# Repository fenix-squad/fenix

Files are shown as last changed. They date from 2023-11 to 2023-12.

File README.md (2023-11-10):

# Что такое Fenix?

Fenix - модель лазерного проектора, разработанная с нуля на олимпиаде
\"Технологии успеха\" командой 548-I. Данный проектор предназначен для
показа лазерных шоу и вывода различных символов на любую твердую
поверхность. Fenix является дешёвым и качественным продуктом, готовым к
использованию сразу после покупки.

# Устройство проектора.

## Материалы

Данный проектор изготовлен из 2 моторов Nema 17, esp 32-S2,micro sd
карты, соединительных проводов и других компонентов. В устройстве
использованы проверенные и современные комплектующие, что обеспечивает
долгую и качественную работу продукта.

## Программное обеспечение

Программное обеспечение написано на языке C++ профессиональными
разработчиками, которые оптимизировали программу. Это позволяет с
комфортом работать с проектором.

## Пользовательский интерфейс

Пользователь может управлять проектором с помощью web-приложения. Оно
написано с помощью фреймворка Svelte на Typescript, а также имеет
красивый и понятный дизайн. В web-приложении есть несколько режимов
работы: «Фигуры», «Текст», «Прямые линии», «Холст».

# Преимущества

-   Fenix собран из качественных комплектующих, которые проверяются
    перед установкой.

-   Доступная цена

-   Понятное управление проектором

# Цена устройства

  Наименование                Цена за штуку в рублях   количество   Сумма
  --------------------------- ------------------------ ------------ -------
  Мотор Nema 17               500                      2            1000
  Драйвер для мотора A4988    70                       2            140
  Esp 32-S2                   150                      1            150
  Триггер быстрой зарядки     50                       1            50
  Корпус устройства           200                      1            200
  Micro Sd карта              80                       1            80
  Модуль для micro Sd карты   20                       1            20
  Провода                     50                       да           50
  Макетная плата              90                       1            90
  Лазер                       100                      1            100
  Детали из пластика          100                      1            100
  Зеркала                     2                        2            4
  Работа                                                            1500
  Прочие расходы              100                      1            100
  Итог:                                                             3584
:::

# Заключение

За неделю наша команда разработала многофункциональный проектор по
доступной цене. Мы знаем что многое можно доработать, но мы считаем, что
уже сейчас нашим продуктом можно пользоваться с комфортом, и создавать
качественные лазерные шоу.

# Благодарность

Наша команда выражает благодарность: **Аверкиной Марине Ильиничне,
Диордице Александру Александровичу, Кудрявцеву Валерию Рудольфовичу,
Бакуну Алексею Дмитриевичу**, а также администрации и педагогическому
коллективу школы №548 за оказанную помощь и поддержку участникам
команды.

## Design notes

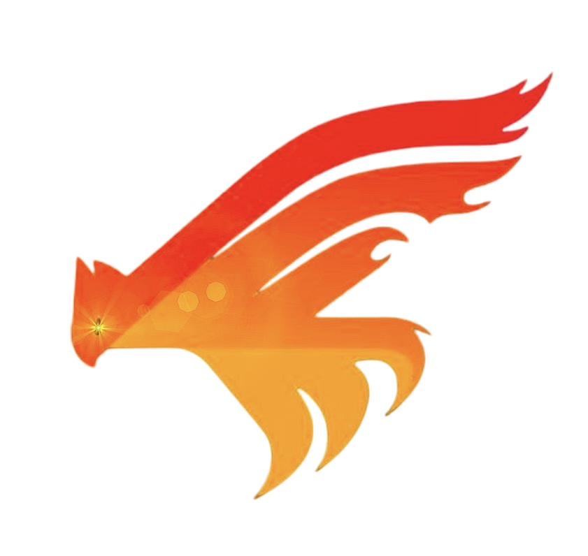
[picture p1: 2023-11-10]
assets/Imagies/Fenix.jpeg

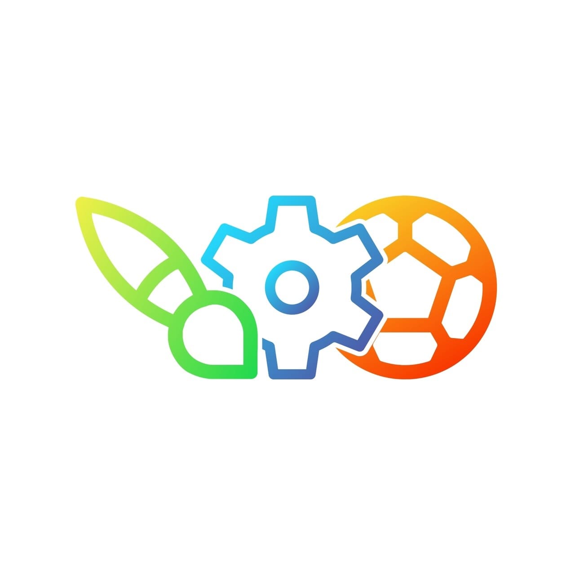
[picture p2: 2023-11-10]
assets/Imagies/BTO.jpeg

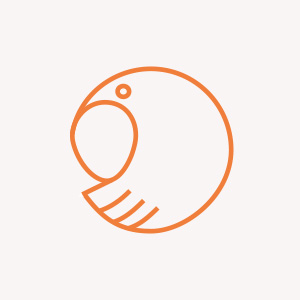
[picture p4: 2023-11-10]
assets/Imagies/Logo_2.jpeg

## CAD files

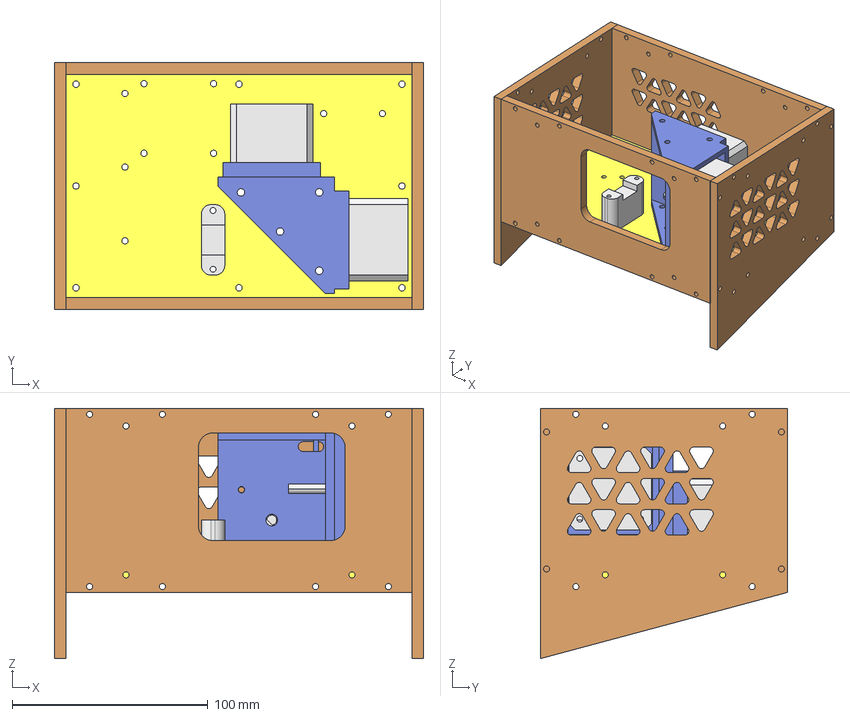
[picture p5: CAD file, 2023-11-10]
product/models/scanatore.FCStd
188.5 x 126.0 x 127.8 mm
scanatore
down-board
nema17
nema018
laser-mount
side-wall
side-wall001
rear-wall
front-wall

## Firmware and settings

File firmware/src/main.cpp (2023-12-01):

#include "deps.cpp"
#include "config.cpp"

#include "logs/log.cpp"

#include "devs/@package.cpp"
#include "laser/@package.cpp"

#include "web/server.cpp"
#include "web/socket.cpp"

#include "types/@package.cpp"
using namespace types;

#include "./math.cpp"
#include <cmath>  


Galvo gx({ .dac=XDAC, .ref=XREF });
Galvo gy({ .dac=YDAC, .ref=YREF });
Engine eng({ .x=&gx, .y=&gy });

Laser laser({ .eng=&eng });


const char *ssid = "{ Fenix }";
const char *pass = "Fenix548";

Group *dvd;
Relygon *bd;


func setup() -> None {
    USB.begin();
    stream.begin();
    SPIFFS.begin();

    ledcSetup(0, FREQ, 5);
    ledcSetup(1, FREQ, 5);
    ledcSetup(2, FREQ, 5);

    ledcAttachPin(RPIN, 0);
    ledcAttachPin(GPIN, 1);
    ledcAttachPin(BPIN, 2);

    eng.speed(spd);
    eng.target({0, 0});
    
    WiFi.mode(WIFI_AP);
    WiFi.softAP(ssid, pass);
    MDNS.begin("fenix");

    WSocket::init();
    WServer::init();

    MDNS.addService("http", "tcp", 80);

    Path *path = new Path();
    Relygon *sq = new Relygon(60, 24);
    Text *tx = (new Text("548"));

    dvd = new Group {
        sq->rotate(45),
        tx->scale(1.8),
    };
    bd = new Relygon(340, 4),

    WSocket::handlers[POINTS] = [&](Vec<u8> &data, u16 len) {
        stream.println("HERE");
        dvd->display(false);
        bd->display(false);

        auto &points = path->points;
        points.resize((len - 1) / 4);

        for (u16 ind = 1; ind < len; ind += 4) {
            u32 point = data[ind] << 24
                        | data[ind + 1] << 16
                        | data[ind + 2] << 8
                        | data[ind + 3];

            i32 x = ((point & (0b11111111'10000000'00000000'00000000)) >> 23) - 255;
            i32 y = 255 - ((point & (0b00000000'01111111'11000000'00000000)) >> 14);

            u8 r = ((point & (0b00000000'00000000'00111110'00000000)) >> 9);
            u8 g = ((point & (0b00000000'00000000'00000001'11110000)) >> 4);
            u8 b = ((point & (0b00000000'00000000'00000000'00001111)) >> 0);

            u8 s = (r != 0) * 255;
            points[(ind - 1) / 4] = { x, y, rgb(s) };
        }
    };

    WSocket::handlers[SPEED] = [](Vec<u8> &data, u16 len) {
        spd = data[1];
    };

    laser.add({
        path,
        dvd,
        bd->rotate(45),
    });
}


u32 last = 0;
i32 sx = 4, sy = 4;
i32 x = 0, y = 0;
i32 s = 0;


func loop() -> None {
    eng.speed(spd);
    laser.tick();

    if (millis() - last > 30) {
        s = (s + 1) % 180;
        x += sx;
        y += sy;

        f32 sc = sin(s  / 180.0 * PI) + 0.7;
        if ((x - 60 * sc) < -200 || (x + 60 * sc) > 200) {
            sx = -sx;
        }
        if ((y - 60 * sc) < -200 || (y + 60 * sc) > 200) {
            sy = -sy;
        }

        dvd->move(x, y);
        dvd->scale(sc);
        last = millis();
    }
}

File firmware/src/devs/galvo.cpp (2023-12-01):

#ifndef __DEVS_STEPPER__
#define __DEVS_STEPPER__


#include <Arduino.h>

#include "logs/log.cpp"

#include "../types/@package.cpp"
using namespace types;


struct Galvo {
    private: i32 cur = 0;
    private: f32 spd = 0;
    private: u8 dac, ref;

    private: struct $Galvo {
        u8 dac;
        u8 ref;
    };

    public: Galvo($Galvo args) {
        auto [dac, ref] = args;

        this->dac = dac;
        this->ref = ref;

        pinMode(dac, OUTPUT);
        pinMode(ref, OUTPUT);
    };

    public: func speed(f32 spd) -> None {
        this->spd = spd;
    };

    public: func target(i32 pos) -> u32 {
        if (pos >= 0) {
            dacWrite(dac, pos);
            digitalWrite(ref, LOW);
        } else {
            dacWrite(dac, 255 - abs(pos));
            digitalWrite(ref, HIGH);
        }
        u32 d = abs(pos - cur);
        u32 t = d * spd;
        this->cur = pos;
        return t;
    };
};


#endif

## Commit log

2023-11-10 Add 3d models and laser cut svg
    [scanatore.FCStd]
2023-11-28 Реорганизация файловой структуры
    [scanatore.FCStd]
2023-11-30 Улучшена совместимость с RGB
2023-11-30 Мелкие изменения
    Добавлен конфигурационный файл и удален старый код
2023-12-01 Доработка WebSocket и оптимизации
2023-12-01 Изменения в объектном менеджере
    Добавлена возможность группировки объектов, а также их смещение на заданные координаты.
2023-12-01 Мелкие изменения
